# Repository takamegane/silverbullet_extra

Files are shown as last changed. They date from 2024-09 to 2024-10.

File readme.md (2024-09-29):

Silverbullet_extra

swanmatch様のSiverbullet44の基板データを元に改変した基板です。
元データ(Silberbullet44)
https://github.com/swanmatch/silverbullet44

主な特徴としては
・MCUをRP2040 Promicroに変更
・LEDを南向きに変更
・ロータリーエンコーダを左右別に最大3つまで搭載可能
・親指クラスタ部はEC12ロータリーエンコーダとTHQWGD001とAZ1UBALLを選択可能
・Vial対応
です。
OLEDも利用できるようにしてありますが、ファーム未実装です。
OLED部分を用いてAZ1UBALLを取り付けることも可能です。

AZ1UBALLを利用する場合、左手→マウススクロール、右手トラックボールとして利用可能です。

ファームはまだ未完成のため、今後改良の余地はあるかと思います。
特に加速モードの切り替え、左右AZ1UBALLの操作切り替えなどは実装したいところです。

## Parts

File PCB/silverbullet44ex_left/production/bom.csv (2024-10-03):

Designator | Footprint | Quantity | Value | LCSC Part #
AZ1UBALL_L1 | AZ1UBALL | 1 | AZ1UBALL
D1, D10, D11, D12, D13, D14, D15, D16, D17, D18, D19, D2, D20, D21, D22, D23, D24, D3, D4, D5, D6, D7, D8, D9 | Diode_SMD | 24 | D
JACK1 | TRRS_MJ-4PP-9 | 1 | MJ-4PP-9
L1, L10, L11, L12, L13, L14, L15, L16, L17, L18, L19, L2, L20, L21, L3, L4, L5, L6, L7, L8, L9 | YS-SK6812MINI-E | 21 | YS-SK6812MINI-E
OLED_L1 | OLED | 1 | OLED
Q1 | SOT-23_Handsoldering | 1 | BSS138
R1 | Resistor-Hybrid-Back | 1 | 1k
R2 | Resistor-Hybrid-Back | 1 | 560
RESET_SW1 | SW_Tactile_SPST_Angled_PTS645Vx39-2LFS | 1 | SW_Push
SW1, SW10, SW11, SW12, SW13, SW14, SW15, SW16, SW17, SW18, SW2, SW20, SW21, SW22, SW3, SW4, SW5, SW6, SW8, SW9 | MX1U_Hotswap | 20 | SW_Push
SW19 | MX1U_Hotswap_RE | 1 | SW_Push
SW23, SW24, SW7_2 | EC12RE | 3 | RotaryEncoder_Switch
SW7 | THQWGD001 | 1 | RotaryEncoder_Switch
U1 | RP2040Promicro | 1 | RP2040Promicro

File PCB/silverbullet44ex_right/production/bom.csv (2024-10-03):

Designator | Footprint | Quantity | Value | LCSC Part #
AZ1UBALL_L2 | AZ1UBALL | 1 | AZ1UBALL
D25, D26, D27, D28, D29, D30, D31, D32, D33, D34, D35, D36, D37, D38, D39, D40, D41, D42, D43, D44, D45, D46, D47, D48 | Diode_SMD | 24 | D
JACK2 | TRRS_MJ-4PP-9 | 1 | MJ-4PP-9
L22, L23, L24, L25, L26, L27, L28, L29, L30, L31, L32, L33, L34, L35, L36, L37, L38, L39, L40, L41, L42 | YS-SK6812MINI-E | 21 | YS-SK6812MINI-E
OLED_L2 | OLED | 1 | OLED
Q2 | SOT-23_Handsoldering | 1 | BSS138
R3 | Resistor-Hybrid-Back | 1 | 1k
R4 | Resistor-Hybrid-Back | 1 | 560
RESET_SW2 | SW_Tactile_SPST_Angled_PTS645Vx39-2LFS | 1 | SW_Push
SW25, SW26, SW27, SW29, SW30, SW31, SW33, SW34, SW35, SW36, SW37, SW38, SW39, SW40, SW41, SW42, SW43, SW45, SW46, SW47 | MX1U_Hotswap | 20 | SW_Push
SW28, SW44, SW48 | EC12RE | 3 | RotaryEncoder_Switch
SW32 | MX1U_Hotswap_RE | 1 | SW_Push
SW44_2 | THQWGD001 | 1 | RotaryEncoder_Switch
U2 | RP2040Promicro | 1 | RP2040Promicro

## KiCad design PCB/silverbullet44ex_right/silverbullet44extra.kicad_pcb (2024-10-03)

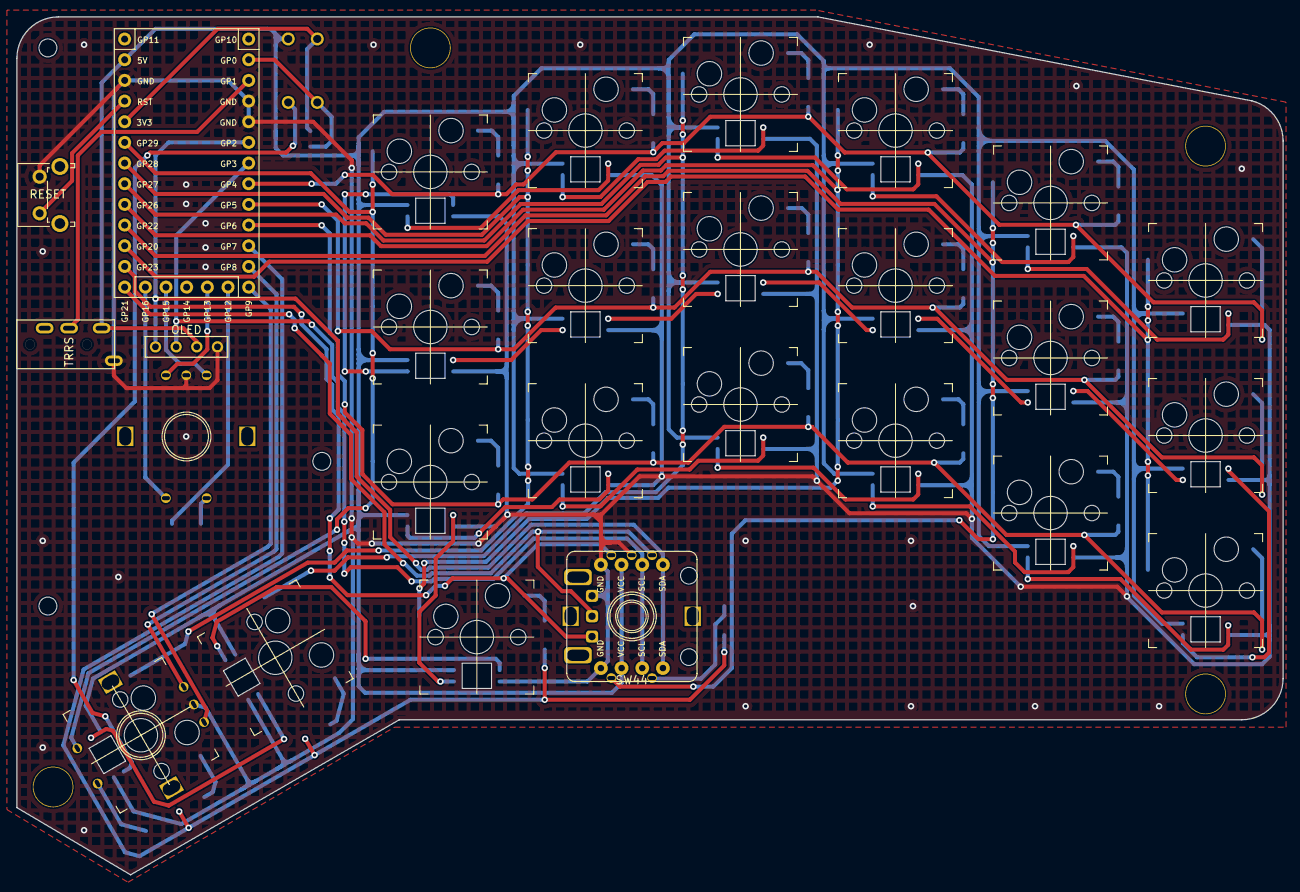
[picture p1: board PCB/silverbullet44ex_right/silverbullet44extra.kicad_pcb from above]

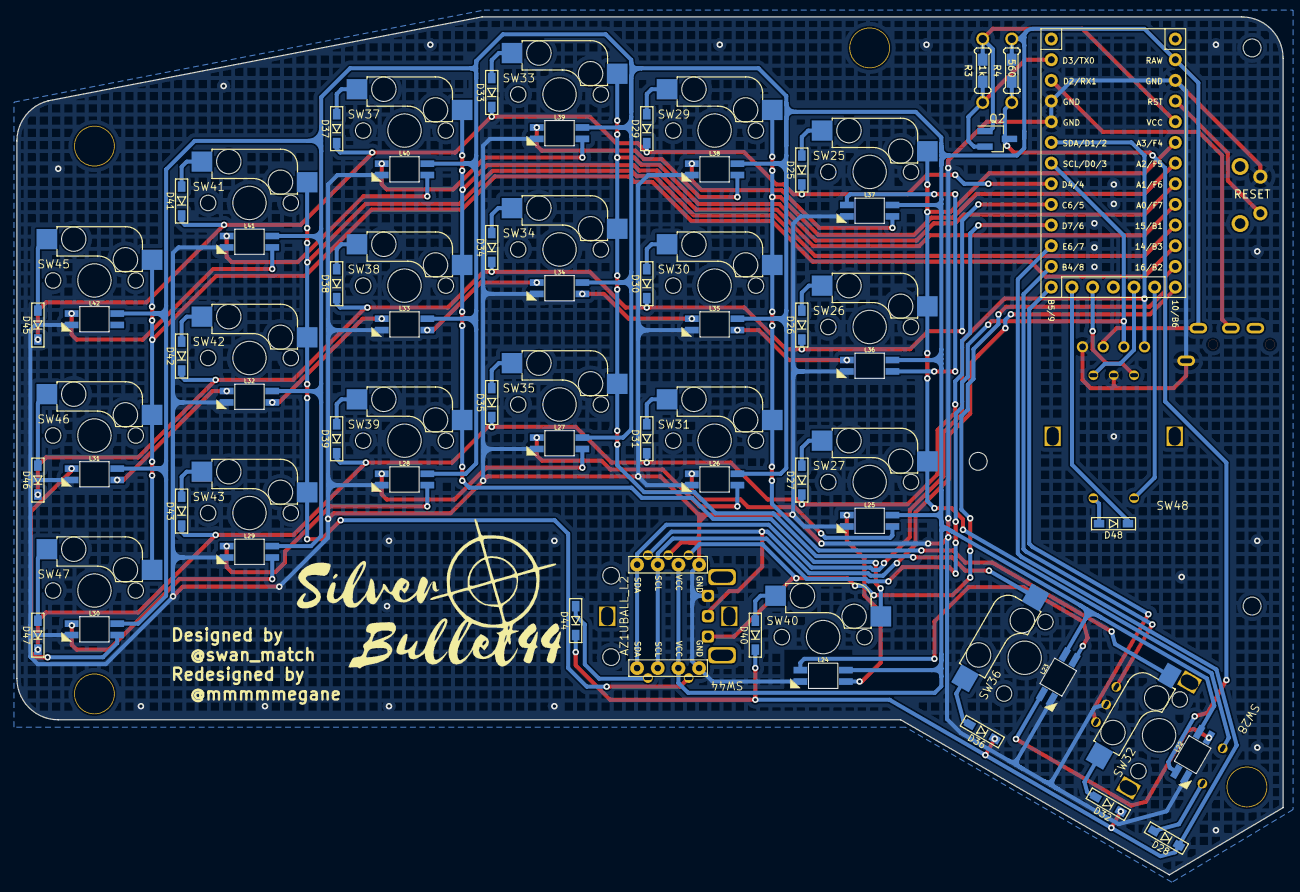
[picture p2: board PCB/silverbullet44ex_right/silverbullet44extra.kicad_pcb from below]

Board: 2 copper layers, 155.6 x 105.4 mm, 86 parts (25 on the bottom side), 71 nets.

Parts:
AZ1UBALL_L2: AZ1UBALL
D25, D26, D27, D28, D29, D30, D31, D32, D33, D34, D35, D36, D37, D38, D39, D40, D41, D42, D43, D44, D45, D46, D47, D48: D; Diode_SMD
G*2: LOGO; silverbullet
J3, J4, J5: Conn_01x01; MountingHole_2.2mm_M2
JACK2: MJ-4PP-9; TRRS_MJ-4PP-9
L22, L23, L24, L25, L26, L27, L28, L29, L30, L31, L32, L33, L34, L35, L36, L37, L38, L39, L40, L41, L42: YS-SK6812MINI-E
OLED_L2: OLED
Q2: BSS138; SOT-23_Handsoldering
R3: 1k; Resistor-Hybrid-Back
R4: 560; Resistor-Hybrid-Back
RESET_SW2: SW_Push; SW_Tactile_SPST_Angled_PTS645Vx39-2LFS
Ref1, Ref2, Ref3, Ref5: Val**; HOLE
SW25, SW26, SW27, SW29, SW30, SW31, SW33, SW34, SW35, SW36, SW37, SW38, SW39, SW40, SW41, SW42, SW43, SW45, SW46, SW47: SW_Push; MX1U_Hotswap
SW28, SW44#2, SW48: RotaryEncoder_Switch; EC12RE
SW32: SW_Push; MX1U_Hotswap_RE
SW44: RotaryEncoder_Switch; THQWGD001
U2: RP2040Promicro

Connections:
+3V3R: Q2.1 (G), R3.1, U2.30 (3V3)
+5VR: AZ1UBALL_L2.3 (VCC), JACK2.D, L22.1 (VDD), L23.1 (VDD), L24.1 (VDD), L25.1 (VDD), L26.1 (VDD), L27.1 (VDD), L28.1 (VDD), L29.1 (VDD), L30.1 (VDD), L31.1 (VDD), L32.1 (VDD), L33.1 (VDD), L34.1 (VDD), L35.1 (VDD), L36.1 (VDD), L37.1 (VDD), L38.1 (VDD), L39.1 (VDD), L40.1 (VDD), L41.1 (VDD), L42.1 (VDD), OLED_L2.3 (VCC), R4.1, U2.33 (5V)
Col7: SW25.1, SW26.1, SW27.1, SW28.S2, U2.29
Col8: SW29.1, SW30.1, SW31.1, SW32.1, U2.28
Col9: SW33.1, SW34.1, SW35.1, SW36.1, U2.27
Col10: SW37.1, SW38.1, SW39.1, SW40.1, U2.26
Col11: SW41.1, SW42.1, SW43.1, SW44#2.S2, U2.22
Col12: SW45.1, SW46.1, SW47.1, U2.20
Col13: SW48.S2, U2.16
DATA_R: JACK2.C, U2.1
GNDR: AZ1UBALL_L2.4 (GND), JACK2.A, L22.3 (VSS), L23.3 (VSS), L24.3 (VSS), L25.3 (VSS), L26.3 (VSS), L27.3 (VSS), L28.3 (VSS), L29.3 (VSS), L30.3 (VSS), L31.3 (VSS), L32.3 (VSS), L33.3 (VSS), L34.3 (VSS), L35.3 (VSS), L36.3 (VSS), L37.3 (VSS), L38.3 (VSS), L39.3 (VSS), L40.3 (VSS), L41.3 (VSS), L42.3 (VSS), OLED_L2.4 (GND), RESET_SW2.2, SW28.C, SW44.C, SW44#2.C, SW48.C, U2.32 (GND), U2.34 (GND), U2.35 (GND)
LED3.3V_R: Q2.2 (S), R3.2, U2.0
LED5V_R: L22.4 (DIN), Q2.3 (D), R4.2
unnamed: D25.2 (A), SW25.2
unnamed: D26.2 (A), SW26.2
unnamed: D27.2 (A), SW27.2
unnamed: D28.2 (A), SW28.S1
unnamed: D29.2 (A), SW29.2
unnamed: D30.2 (A), SW30.2
unnamed: D31.2 (A), SW31.2
unnamed: D32.2 (A), SW32.2
unnamed: D33.2 (A), SW33.2
unnamed: D34.2 (A), SW34.2
unnamed: D35.2 (A), SW35.2
unnamed: D36.2 (A), SW36.2
unnamed: D37.2 (A), SW37.2
unnamed: D38.2 (A), SW38.2
unnamed: D39.2 (A), SW39.2
unnamed: D40.2 (A), SW40.2
unnamed: D41.2 (A), SW41.2
unnamed: D42.2 (A), SW42.2
unnamed: D43.2 (A), SW43.2
unnamed: D44.2 (A), SW44#2.S1
unnamed: D45.2 (A), SW45.2
unnamed: D46.2 (A), SW46.2
unnamed: D47.2 (A), SW47.2
unnamed: D48.2 (A), SW48.S1
unnamed: L22.2 (DOUT), L23.4 (DIN)
unnamed: L23.2 (DOUT), L24.4 (DIN)
unnamed: L24.2 (DOUT), L25.4 (DIN)
unnamed: L25.2 (DOUT), L26.4 (DIN)
unnamed: L26.2 (DOUT), L27.4 (DIN)
unnamed: L27.2 (DOUT), L28.4 (DIN)
unnamed: L28.2 (DOUT), L29.4 (DIN)
unnamed: L29.2 (DOUT), L30.4 (DIN)
unnamed: L30.2 (DOUT), L31.4 (DIN)
unnamed: L31.2 (DOUT), L32.4 (DIN)
unnamed: L32.2 (DOUT), L33.4 (DIN)
unnamed: L33.2 (DOUT), L34.4 (DIN)
unnamed: L34.2 (DOUT), L35.4 (DIN)
unnamed: L35.2 (DOUT), L36.4 (DIN)
unnamed: L36.2 (DOUT), L37.4 (DIN)
unnamed: L37.2 (DOUT), L38.4 (DIN)
unnamed: L38.2 (DOUT), L39.4 (DIN)
unnamed: L39.2 (DOUT), L40.4 (DIN)
unnamed: L40.2 (DOUT), L41.4 (DIN)
unnamed: L41.2 (DOUT), L42.4 (DIN)
RE4A: SW28.A, U2.8
RE4B: SW28.B, U2.9
RE5A: SW44.A, SW44#2.A, U2.23
RE5B: SW44.B, SW44#2.B, U2.21
RE6A: SW48.A, U2.13
RE6B: SW48.B, U2.15
RESET_R: RESET_SW2.1, U2.31 (RST)
Row5: D25.1 (K), D29.1 (K), D33.1 (K), D37.1 (K), D41.1 (K), D45.1 (K), U2.4
Row6: D26.1 (K), D30.1 (K), D34.1 (K), D38.1 (K), D42.1 (K), D46.1 (K), U2.5
Row7: D27.1 (K), D31.1 (K), D35.1 (K), D39.1 (K), D43.1 (K), D47.1 (K), U2.6
Row8: D28.1 (K), D32.1 (K), D36.1 (K), D40.1 (K), D44.1 (K), U2.7
Row9: D48.1 (K), U2.12
SCL_R: AZ1UBALL_L2.2 (SCL), OLED_L2.2 (SCL), U2.3
SDA_R: AZ1UBALL_L2.1 (SDA), OLED_L2.1 (SDA), U2.2

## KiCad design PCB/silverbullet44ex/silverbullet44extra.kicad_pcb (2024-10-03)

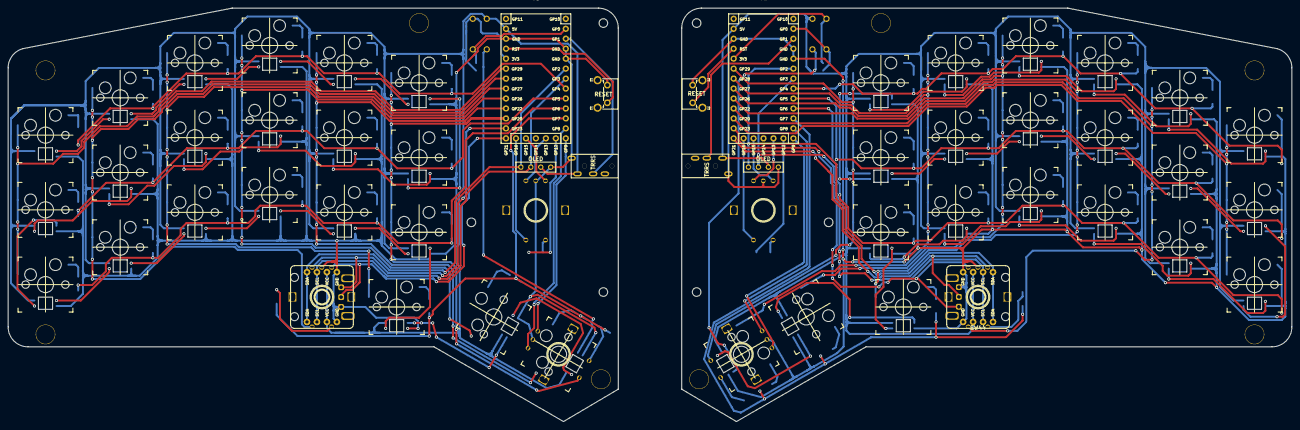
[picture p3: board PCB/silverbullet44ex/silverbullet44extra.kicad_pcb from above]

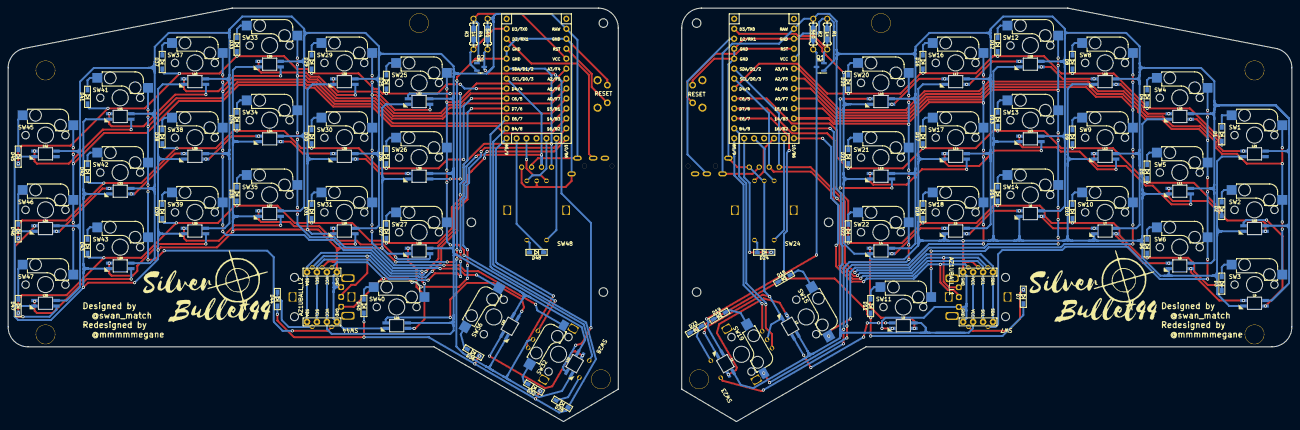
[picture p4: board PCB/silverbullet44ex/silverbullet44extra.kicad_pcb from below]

Board: 2 copper layers, 327.3 x 105.4 mm, 172 parts (50 on the bottom side), 142 nets.

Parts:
AZ1UBALL_L1, AZ1UBALL_L2: AZ1UBALL
D1, D2, D3, D4, D5, D6, D7, D8, D9, D10, D11, D12, D13, D14, D15, D16, D17, D18, D19, D20, D21, D22, D23, D24, D25, D26, D27, D28, D29, D30, D31, D32, D33, D34, D35, D36, D37, D38, D39, D40, D41, D42, D43, D44, D45, D46, D47, D48: D; Diode_SMD
G*2, G*2#2: LOGO; silverbullet
J3, J3#2, J4, J4#2, J5, J5#2: Conn_01x01; MountingHole_2.2mm_M2
JACK1, JACK2: MJ-4PP-9; TRRS_MJ-4PP-9
L1, L2, L3, L4, L5, L6, L7, L8, L9, L10, L11, L12, L13, L14, L15, L16, L17, L18, L19, L20, L21, L22, L23, L24, L25, L26, L27, L28, L29, L30, L31, L32, L33, L34, L35, L36, L37, L38, L39, L40, L41, L42: YS-SK6812MINI-E
OLED_L1, OLED_L2: OLED
Q1, Q2: BSS138; SOT-23
R1, R3: 1k; Resistor-Hybrid-Back
R2, R4: 560; Resistor-Hybrid-Back
RESET_SW1, RESET_SW2: SW_Push; SW_Tactile_SPST_Angled_PTS645Vx39-2LFS
Ref1, Ref1#2, Ref2, Ref2#2, Ref3, Ref3#2, Ref5, Ref5#2: Val**; HOLE
SW1, SW2, SW3, SW4, SW5, SW6, SW8, SW9, SW10, SW11, SW12, SW13, SW14, SW15, SW16, SW17, SW18, SW20, SW21, SW22, SW25, SW26, SW27, SW29, SW30, SW31, SW33, SW34, SW35, SW36, SW37, SW38, SW39, SW40, SW41, SW42, SW43, SW45, SW46, SW47: SW_Push; MX1U_Hotswap
SW7, SW44: RotaryEncoder_Switch; THQWGD001
SW7#2, SW23, SW24, SW28, SW44#2, SW48: RotaryEncoder_Switch; EC12RE
SW19, SW32: SW_Push; MX1U_Hotswap_RE
U1, U2: RP2040Promicro

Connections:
+3V3: Q1.1 (G), R1.1, U1.30 (3V3)
+3V3R: Q2.1 (G), R3.1, U2.30 (3V3)
+5V: AZ1UBALL_L1.3 (VCC), JACK1.D, L1.1 (VDD), L2.1 (VDD), L3.1 (VDD), L4.1 (VDD), L5.1 (VDD), L6.1 (VDD), L7.1 (VDD), L8.1 (VDD), L9.1 (VDD), L10.1 (VDD), L11.1 (VDD), L12.1 (VDD), L13.1 (VDD), L14.1 (VDD), L15.1 (VDD), L16.1 (VDD), L17.1 (VDD), L18.1 (VDD), L19.1 (VDD), L20.1 (VDD), L21.1 (VDD), OLED_L1.3 (VCC), R2.1, U1.33 (5V)
+5VR: AZ1UBALL_L2.3 (VCC), JACK2.D, L22.1 (VDD), L23.1 (VDD), L24.1 (VDD), L25.1 (VDD), L26.1 (VDD), L27.1 (VDD), L28.1 (VDD), L29.1 (VDD), L30.1 (VDD), L31.1 (VDD), L32.1 (VDD), L33.1 (VDD), L34.1 (VDD), L35.1 (VDD), L36.1 (VDD), L37.1 (VDD), L38.1 (VDD), L39.1 (VDD), L40.1 (VDD), L41.1 (VDD), L42.1 (VDD), OLED_L2.3 (VCC), R4.1, U2.33 (5V)
Col0: SW1.1, SW2.1, SW3.1, U1.29
Col1: SW4.1, SW5.1, SW6.1, SW7#2.S2, U1.28
Col2: SW8.1, SW9.1, SW10.1, SW11.1, U1.27
Col3: SW12.1, SW13.1, SW14.1, SW15.1, U1.26
Col4: SW16.1, SW17.1, SW18.1, SW19.1, U1.22
Col5: SW20.1, SW21.1, SW22.1, SW23.S2, U1.20
Col6: SW24.S2, U1.16
Col7: SW25.1, SW26.1, SW27.1, SW28.S2, U2.29
Col8: SW29.1, SW30.1, SW31.1, SW32.1, U2.28
Col9: SW33.1, SW34.1, SW35.1, SW36.1, U2.27
Col10: SW37.1, SW38.1, SW39.1, SW40.1, U2.26
Col11: SW41.1, SW42.1, SW43.1, SW44#2.S2, U2.22
Col12: SW45.1, SW46.1, SW47.1, U2.20
Col13: SW48.S2, U2.16
DATA_L: JACK1.C, U1.1
DATA_R: JACK2.C, U2.1
GND: AZ1UBALL_L1.4 (GND), JACK1.A, L1.3 (VSS), L2.3 (VSS), L3.3 (VSS), L4.3 (VSS), L5.3 (VSS), L6.3 (VSS), L7.3 (VSS), L8.3 (VSS), L9.3 (VSS), L10.3 (VSS), L11.3 (VSS), L12.3 (VSS), L13.3 (VSS), L14.3 (VSS), L15.3 (VSS), L16.3 (VSS), L17.3 (VSS), L18.3 (VSS), L19.3 (VSS), L20.3 (VSS), L21.3 (VSS), OLED_L1.4 (GND), RESET_SW1.2, SW7.C, SW7#2.C, SW23.C, SW24.C, U1.32 (GND), U1.34 (GND), U1.35 (GND)
GNDR: AZ1UBALL_L2.4 (GND), JACK2.A, L22.3 (VSS), L23.3 (VSS), L24.3 (VSS), L25.3 (VSS), L26.3 (VSS), L27.3 (VSS), L28.3 (VSS), L29.3 (VSS), L30.3 (VSS), L31.3 (VSS), L32.3 (VSS), L33.3 (VSS), L34.3 (VSS), L35.3 (VSS), L36.3 (VSS), L37.3 (VSS), L38.3 (VSS), L39.3 (VSS), L40.3 (VSS), L41.3 (VSS), L42.3 (VSS), OLED_L2.4 (GND), RESET_SW2.2, SW28.C, SW44.C, SW44#2.C, SW48.C, U2.32 (GND), U2.34 (GND), U2.35 (GND)
LED3.3V_L: Q1.2 (S), R1.2, U1.0
LED3.3V_R: Q2.2 (S), R3.2, U2.0
LED5V_L: L1.4 (DIN), Q1.3 (D), R2.2
LED5V_R: L22.4 (DIN), Q2.3 (D), R4.2
unnamed: D1.2 (A), SW1.2
unnamed: D2.2 (A), SW2.2
unnamed: D3.2 (A), SW3.2
unnamed: D4.2 (A), SW4.2
unnamed: D5.2 (A), SW5.2
unnamed: D6.2 (A), SW6.2
unnamed: D7.2 (A), SW7#2.S1
unnamed: D8.2 (A), SW8.2
unnamed: D9.2 (A), SW9.2
unnamed: D10.2 (A), SW10.2
unnamed: D11.2 (A), SW11.2
unnamed: D12.2 (A), SW12.2
unnamed: D13.2 (A), SW13.2
unnamed: D14.2 (A), SW14.2
unnamed: D15.2 (A), SW15.2
unnamed: D16.2 (A), SW16.2
unnamed: D17.2 (A), SW17.2
unnamed: D18.2 (A), SW18.2
unnamed: D19.2 (A), SW19.2
unnamed: D20.2 (A), SW20.2
unnamed: D21.2 (A), SW21.2
unnamed: D22.2 (A), SW22.2
unnamed: D23.2 (A), SW23.S1
unnamed: D24.2 (A), SW24.S1
unnamed: D25.2 (A), SW25.2
unnamed: D26.2 (A), SW26.2
unnamed: D27.2 (A), SW27.2
unnamed: D28.2 (A), SW28.S1
unnamed: D29.2 (A), SW29.2
unnamed: D30.2 (A), SW30.2
unnamed: D31.2 (A), SW31.2
unnamed: D32.2 (A), SW32.2
unnamed: D33.2 (A), SW33.2
unnamed: D34.2 (A), SW34.2
unnamed: D35.2 (A), SW35.2
unnamed: D36.2 (A), SW36.2
unnamed: D37.2 (A), SW37.2
unnamed: D38.2 (A), SW38.2
unnamed: D39.2 (A), SW39.2
unnamed: D40.2 (A), SW40.2
unnamed: D41.2 (A), SW41.2
unnamed: D42.2 (A), SW42.2
unnamed: D43.2 (A), SW43.2
unnamed: D44.2 (A), SW44#2.S1
unnamed: D45.2 (A), SW45.2
unnamed: D46.2 (A), SW46.2
unnamed: D47.2 (A), SW47.2
unnamed: D48.2 (A), SW48.S1
unnamed: L1.2 (DOUT), L2.4 (DIN)
unnamed: L2.2 (DOUT), L3.4 (DIN)
unnamed: L3.2 (DOUT), L4.4 (DIN)
unnamed: L4.2 (DOUT), L5.4 (DIN)
unnamed: L5.2 (DOUT), L6.4 (DIN)
unnamed: L6.2 (DOUT), L7.4 (DIN)
unnamed: L7.2 (DOUT), L8.4 (DIN)
unnamed: L8.2 (DOUT), L9.4 (DIN)
unnamed: L9.2 (DOUT), L10.4 (DIN)
unnamed: L10.2 (DOUT), L11.4 (DIN)
unnamed: L11.2 (DOUT), L12.4 (DIN)
unnamed: L12.2 (DOUT), L13.4 (DIN)
unnamed: L13.2 (DOUT), L14.4 (DIN)
unnamed: L14.2 (DOUT), L15.4 (DIN)
unnamed: L15.2 (DOUT), L16.4 (DIN)
unnamed: L16.2 (DOUT), L17.4 (DIN)
unnamed: L17.2 (DOUT), L18.4 (DIN)
unnamed: L18.2 (DOUT), L19.4 (DIN)
unnamed: L19.2 (DOUT), L20.4 (DIN)
unnamed: L20.2 (DOUT), L21.4 (DIN)
unnamed: L22.2 (DOUT), L23.4 (DIN)
unnamed: L23.2 (DOUT), L24.4 (DIN)
unnamed: L24.2 (DOUT), L25.4 (DIN)
unnamed: L25.2 (DOUT), L26.4 (DIN)
unnamed: L26.2 (DOUT), L27.4 (DIN)
unnamed: L27.2 (DOUT), L28.4 (DIN)
unnamed: L28.2 (DOUT), L29.4 (DIN)
unnamed: L29.2 (DOUT), L30.4 (DIN)
unnamed: L30.2 (DOUT), L31.4 (DIN)
unnamed: L31.2 (DOUT), L32.4 (DIN)
unnamed: L32.2 (DOUT), L33.4 (DIN)
unnamed: L33.2 (DOUT), L34.4 (DIN)
unnamed: L34.2 (DOUT), L35.4 (DIN)
unnamed: L35.2 (DOUT), L36.4 (DIN)
unnamed: L36.2 (DOUT), L37.4 (DIN)
unnamed: L37.2 (DOUT), L38.4 (DIN)
unnamed: L38.2 (DOUT), L39.4 (DIN)
unnamed: L39.2 (DOUT), L40.4 (DIN)
unnamed: L40.2 (DOUT), L41.4 (DIN)
unnamed: L41.2 (DOUT), L42.4 (DIN)
RE1A: SW23.A, U1.8
RE1B: SW23.B, U1.9
RE2A: SW7.A, SW7#2.A, U1.23
RE2B: SW7.B, SW7#2.B, U1.21
RE3A: SW24.A, U1.13
RE3B: SW24.B, U1.15
RE4A: SW28.A, U2.8
RE4B: SW28.B, U2.9
RE5A: SW44.A, SW44#2.A, U2.23
RE5B: SW44.B, SW44#2.B, U2.21
RE6A: SW48.A, U2.13
RE6B: SW48.B, U2.15
RESET_L: RESET_SW1.1, U1.31 (RST)
RESET_R: RESET_SW2.1, U2.31 (RST)
Row0: D1.1 (K), D4.1 (K), D8.1 (K), D12.1 (K), D16.1 (K), D20.1 (K), U1.4
Row1: D2.1 (K), D5.1 (K), D9.1 (K), D13.1 (K), D17.1 (K), D21.1 (K), U1.5
Row2: D3.1 (K), D6.1 (K), D10.1 (K), D14.1 (K), D18.1 (K), D22.1 (K), U1.6
Row3: D7.1 (K), D11.1 (K), D15.1 (K), D19.1 (K), D23.1 (K), U1.7
Row4: D24.1 (K), U1.12
Row5: D25.1 (K), D29.1 (K), D33.1 (K), D37.1 (K), D41.1 (K), D45.1 (K), U2.4
Row6: D26.1 (K), D30.1 (K), D34.1 (K), D38.1 (K), D42.1 (K), D46.1 (K), U2.5
Row7: D27.1 (K), D31.1 (K), D35.1 (K), D39.1 (K), D43.1 (K), D47.1 (K), U2.6
Row8: D28.1 (K), D32.1 (K), D36.1 (K), D40.1 (K), D44.1 (K), U2.7
Row9: D48.1 (K), U2.12
SCL_L: AZ1UBALL_L1.2 (SCL), OLED_L1.2 (SCL), U1.3
SCL_R: AZ1UBALL_L2.2 (SCL), OLED_L2.2 (SCL), U2.3
SDA_L: AZ1UBALL_L1.1 (SDA), OLED_L1.1 (SDA), U1.2
SDA_R: AZ1UBALL_L2.1 (SDA), OLED_L2.1 (SDA), U2.2

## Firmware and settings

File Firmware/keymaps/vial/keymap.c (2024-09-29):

#include QMK_KEYBOARD_H

enum my_keycode{
  NORMAL = QK_KB_0,
  ACCEL
};

const uint16_t PROGMEM keymaps[][MATRIX_ROWS][MATRIX_COLS] = {
    [0] = LAYOUT_split_3x6_3(
        KC_TAB,  KC_Q,    KC_W,    KC_E,    KC_R,    KC_T,                               KC_Y,    KC_U,    KC_I,    KC_O,    KC_P,    KC_BSPC,
        KC_LCTL, KC_A,    KC_S,    KC_D,    KC_F,    KC_G,   KC_MUTE,        KC_MUTE,    KC_H,    KC_J,    KC_K,    KC_L,    KC_SCLN, KC_QUOT,
        KC_LSFT, KC_Z,    KC_X,    KC_C,    KC_V,    KC_B,                               KC_N,    KC_M,    KC_COMM, KC_DOT,  KC_SLSH, KC_RSFT,
                 KC_LGUI, KC_BSPC, KC_LGUI, KC_BSPC, KC_SPC,                             KC_BSPC, KC_SPC,   KC_SPC,  KC_ENT, KC_RALT
    ),
    [1] = LAYOUT_split_3x6_3(
        KC_TAB,  KC_Q,    KC_W,    KC_E,    KC_R,    KC_T,                               KC_Y,    KC_U,    KC_I,    KC_O,    KC_P,    KC_BSPC,
        KC_LCTL, KC_A,    KC_S,    KC_D,    KC_F,    KC_G,   KC_MUTE,        KC_MUTE,    KC_H,    KC_J,    KC_K,    KC_L,    KC_SCLN, KC_QUOT,
        KC_LSFT, KC_Z,    KC_X,    KC_C,    KC_V,    KC_B,                               KC_N,    KC_M,    KC_COMM, KC_DOT,  KC_SLSH, KC_RSFT,
                 KC_LGUI, KC_BSPC, KC_LGUI, KC_BSPC, KC_SPC,                             KC_BSPC, KC_SPC,   KC_SPC,  KC_ENT, KC_RALT
    ),
    [2] = LAYOUT_split_3x6_3(
        KC_TAB,  KC_Q,    KC_W,    KC_E,    KC_R,    KC_T,                               KC_Y,    KC_U,    KC_I,    KC_O,    KC_P,    KC_BSPC,
        KC_LCTL, KC_A,    KC_S,    KC_D,    KC_F,    KC_G,   KC_MUTE,        KC_MUTE,    KC_H,    KC_J,    KC_K,    KC_L,    KC_SCLN, KC_QUOT,
        KC_LSFT, KC_Z,    KC_X,    KC_C,    KC_V,    KC_B,                               KC_N,    KC_M,    KC_COMM, KC_DOT,  KC_SLSH, KC_RSFT,
                 KC_LGUI, KC_BSPC, KC_LGUI, KC_BSPC, KC_SPC,                             KC_BSPC, KC_SPC,   KC_SPC,  KC_ENT, KC_RALT
    ),
    [3] = LAYOUT_split_3x6_3(
        KC_TAB,  KC_Q,    KC_W,    KC_E,    KC_R,    KC_T,                               KC_Y,    KC_U,    KC_I,    KC_O,    KC_P,    KC_BSPC,
        KC_LCTL, KC_A,    KC_S,    KC_D,    KC_F,    KC_G,   KC_MUTE,        KC_MUTE,    KC_H,    KC_J,    KC_K,    KC_L,    KC_SCLN, KC_QUOT,
        KC_LSFT, KC_Z,    KC_X,    KC_C,    KC_V,    KC_B,                               KC_N,    KC_M,    KC_COMM, KC_DOT,  KC_SLSH, KC_RSFT,
                 KC_LGUI, KC_BSPC, KC_LGUI, KC_BSPC, KC_SPC,                             KC_BSPC, KC_SPC,   KC_SPC,  KC_ENT, KC_RALT
    )
};


const uint16_t PROGMEM encoder_map[][NUM_ENCODERS][NUM_DIRECTIONS] = {
    [0] = { ENCODER_CCW_CW(KC_C, KC_D),
            ENCODER_CCW_CW(KC_C, KC_D), 
            ENCODER_CCW_CW(KC_E, KC_F), 
            ENCODER_CCW_CW(KC_G, KC_H), 
            ENCODER_CCW_CW(KC_I, KC_J),
            ENCODER_CCW_CW(KC_G, KC_H) },
    [1] = { ENCODER_CCW_CW(KC_C, KC_D),
            ENCODER_CCW_CW(KC_C, KC_D), 
            ENCODER_CCW_CW(KC_E, KC_F), 
            ENCODER_CCW_CW(KC_G, KC_H), 
            ENCODER_CCW_CW(KC_I, KC_J),
            ENCODER_CCW_CW(KC_G, KC_H) },
    [2] = { ENCODER_CCW_CW(KC_C, KC_D),
            ENCODER_CCW_CW(KC_C, KC_D), 
            ENCODER_CCW_CW(KC_E, KC_F), 
            ENCODER_CCW_CW(KC_G, KC_H), 
            ENCODER_CCW_CW(KC_I, KC_J),
            ENCODER_CCW_CW(KC_G, KC_H) },
    [3] = { ENCODER_CCW_CW(KC_C, KC_D),
            ENCODER_CCW_CW(KC_C, KC_D), 
            ENCODER_CCW_CW(KC_E, KC_F), 
            ENCODER_CCW_CW(KC_G, KC_H), 
            ENCODER_CCW_CW(KC_I, KC_J),
            ENCODER_CCW_CW(KC_G, KC_H) },
};


bool process_record_user(uint16_t keycode, keyrecord_t *record) {
  switch (keycode) {
    case NORMAL:
      pimoroni_trackball_set_cpi(128*125); //Default Speed
      break;
    case ACCEL:                                      
      pimoroni_trackball_set_cpi(3*128*125); // x3 Speed
      break;
  }
  return true;
}

// Default Accellaration Mode
void pointing_device_init_kb(void) {
    //uint8_t addr=0x14;
    uint8_t addr=0x0a<<1;
    //uint8_t data[]={0x90, 0x00};    // AZ1UBALL normal speed mode
    uint8_t data[]={0x91, 0x00};      // AZ1UBALL accellaration mode
    uint16_t timeout=100;             // in milli-seconds
    i2c_status_t status;
    status  = i2c_transmit (addr, data, 2, timeout);
    if (status != 0) {
        return;
    }   
}

void keyboard_post_init_user(void) {
    pointing_device_set_cpi_on_side(true,500); //Set cpi on left side to a low value for slower scrolling.
    pointing_device_set_cpi_on_side(false, 8000); //Set cpi on right side to a reasonable value for mousing.
}

report_mouse_t pointing_device_task_combined_user(report_mouse_t left_report, report_mouse_t right_report) {
    left_report.h = left_report.x;
    left_report.v = left_report.y;
    left_report.x = 0;
    left_report.y = 0;
    return pointing_device_combine_reports(left_report, right_report);
}
